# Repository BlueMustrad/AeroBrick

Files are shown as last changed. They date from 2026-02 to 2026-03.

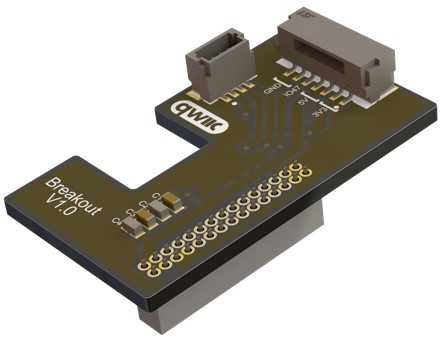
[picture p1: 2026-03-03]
Images/AeroBrick Breakout Board Image.jpg

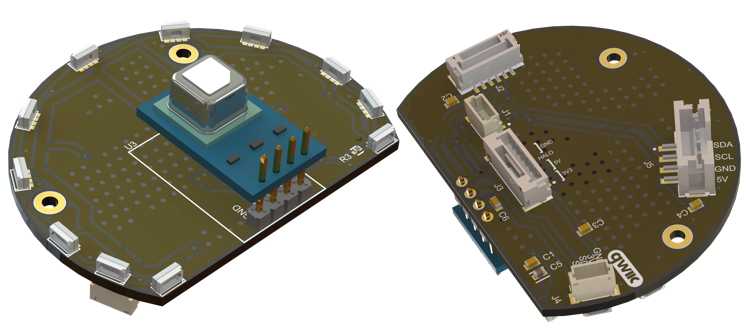
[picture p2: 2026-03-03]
Images/AeroBrick MainBoard Image.jpg

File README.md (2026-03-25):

# AERO BRICK
A fully open-source and easy-to-build air-quality monitor designed for workshops, maker spaces, and home labs. It continuously tracks particulate matter (PM1–PM10), CO₂, VOCs, temperature, humidity, pressure, and hazardous chemicals, turning the air into actionable data.

Long-term exposure to fumes and poor ventilation is a real concern, especially in the form of soldering, 3D printing, or working with chemicals. As someone who is always working on a project, I come in contact with these more often than I should. AeroBrick solves this in that it's built to live right next to your workbench or printers, providing real-time monitoring and alerts when air quality begins to degrade, so you can act immediately instead of guessing.

Now you may ask, "Can't I buy one from Amazon and have it in my workshop within a day?" To which I say that these off-the-shelf air-quality monitors can cost $300–$400 and track only basic metrics like temperature or generic VOC levels. Whereas AeroBrick can be assembled in just a few days, while having a hell of a time, using readily available components, resulting in lab-grade monitoring at a fraction of the cost.

# The Design
Go to the [Images folder](https://github.com/BlueMustrad/AeroBrick/tree/main/Images) for all pictures!

## THE [FULL ASSEMBLY](https://github.com/BlueMustrad/AeroBrick/blob/main/AeroBrick%20Full%20Assembly.step)!!


### Just the housing in [Fusion](https://github.com/BlueMustrad/AeroBrick/tree/main/3D%20Files/f3d%20Files):




### And in [Bambu Studio](https://github.com/BlueMustrad/AeroBrick/tree/main/3D%20Files/3mf%20Files) for 3D printing!


### To go with it, you also need these [PCBs](https://github.com/BlueMustrad/AeroBrick/tree/main/PCBs%20and%20Circuitry):




### [Schematic](https://github.com/BlueMustrad/AeroBrick/blob/main/Documents/AeroBrick%20Electrical%20Schematic.pdf)!
AeroBrick Electrical Schematic (2)_page-0001

# [Bill of Materials](https://github.com/BlueMustrad/AeroBrick/blob/main/AeroBrick%20Hardware%20BOM.csv)
Disclaimer: These prices do not factor in shipping or taxes!

| Item | Type | Quantity | Price (USD) | Item Total (USD) | Link |
|---|---|---|---|---|---|
| T-Display S3 Long | Screen | 1 | $32.13 | $32.13 | [LilyGo](https://lilygo.cc/en-us/products/t-display-s3-long?variant=44211063390389) |
| SEN54-SDN-T | Sensor | 1 | $26.85 | $26.85 | [DigiKey](https://www.digikey.com/en/products/detail/sensirion-ag/SEN54-SDN-T/15903868) |
| BME280 | Sensor | 1 | $14.95 | $14.95 | [DigiKey](https://www.digikey.com/en/products/detail/adafruit-industries-llc/2652/5604372) |
| SEN0377 | Sensor | 1 | $39.90 | $39.90 | [DigiKey](https://www.digikey.com/en/products/detail/dfrobot/SEN0377/15848107) |
| SCD41 | Sensor | 1 | $28.99 | $28.99 | [Amazon](https://www.amazon.com/HiLetgo-Temperature-Humidity-Communication-Monitoring/dp/B0CDWXWCS5) |
| Qwiic Cable (50mm) | Cable | 2 | $1.50 | $3.00 | [DigiKey](https://www.digikey.com/en/products/detail/sparkfun-electronics/17260/13629028) |
| JST GHR-06V-S | Connector | 2 | $0.15 | $0.30 | [DigiKey](https://www.digikey.com/en/products/detail/jst-sales-america-inc/GHR-06V-S/807818) |
| JST GHR-07V-S | Connector | 2 | $0.14 | $0.28 | [DigiKey](https://www.digikey.com/en/products/detail/jst-sales-america-inc/GHR-07V-S/807819) |
| JST PHR-4 | Connector | 2 | $0.10 | $0.20 | [DigiKey](https://www.digikey.com/en/products/detail/jst-sales-america-inc/PHR-4/608606) |
| Amphenol 68604-804HLF | Connector | 1 | $0.53 | $0.53 | [DigiKey](https://www.digikey.com/en/products/detail/amphenol-fci/68604-804HLF/11606373) |
| JST ASPHSPH24K51 | Connector | 4 | $0.33 | $1.32 | [DigiKey](https://www.digikey.com/en/products/detail/jst-sales-america-inc/ASPHSPH24K51/6009457) |
| JST AGHGH28K51 | Connector | 12 | $0.39 | $4.68 | [DigiKey](https://www.digikey.com/en/products/detail/jst-sales-america-inc/AGHGH28K51/6009448) |
| Custom Made Mainboard | PCB | 5 | $1.20 | $6.00 | JLCPCB (+ $10-15 for stencil) |
| Custom Made Breakout Board | PCB | 5 | $1.20 | $6.00 | JLCPCB (+ $10-15 for stencil) |
| Mainboard Components | Components | — | — | $21.00 | See [PCB files](https://github.com/BlueMustrad/AeroBrick/blob/main/PCBs%20and%20Circuitry/Main%20Board/AeroBrick%20Mainboard%20BOM.csv) for details |
| Breakout Board Components | Components | — | — | $7.00 | See [PCB files](https://github.com/BlueMustrad/AeroBrick/blob/main/PCBs%20and%20Circuitry/Breakout%20Board/AeroBrick%20Breakout%20BOM.csv) for details |
| Hardware Total (as of 02/26) | | | | $193.13 | |

| Item | Total Price | Description |
| ---- | --- | --- |
| Fasteners | $7 | Screws, heat-set inserts, bolts, and washers |
| PCB Stencils | $22.06 | Used to add solder paste to the bare PCB |
| Hidden Costs | ~$125 | Shipping/taxes/tariffs :( |
| **Final Total (as of 03/26)** | | **$347.19** |

### **Additional Considerations (see [Other Parts](https://github.com/BlueMustrad/AeroBrick/blob/main/README.md) for details), not included in the BOM:**
- Screws
- 3D-printing Filament
- Heat-set Inserts
- Solder Paste
- Superglue
- Isopropyl Alcohol

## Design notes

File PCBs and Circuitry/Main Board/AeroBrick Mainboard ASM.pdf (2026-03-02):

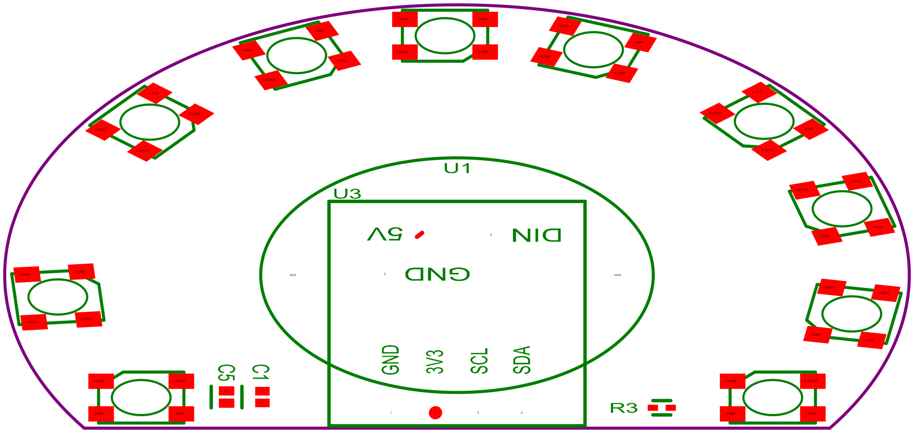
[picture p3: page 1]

4-DIN

1 -VD D

3 -GND

2-DOUT

4-DIN

3 -GND

1 -VDD

2 -D OUT

4 -D IN

1 -VD D

2 -D OUT

3 -GND

2

1

1 -VD D

1

2

2 -D OUT

MH1

4-DIN

3 -GND

3

1

1 -VD D

2-DOUT

1

2 | 3

4-DIN

3 -GND

2

4

2 -D OUT

1 -VD D

MH2

3 -GND

4-DIN

1 | 2

2-DOUT

4-DIN

3 -GND

1 -VD D

3 -GND

2-DOUT

4-DIN

1 -VD D

2 -D OUT

3-GND

3 -GND

2-DOUT

1 -VD D

4-DIN

4-DIN

1 -VD D

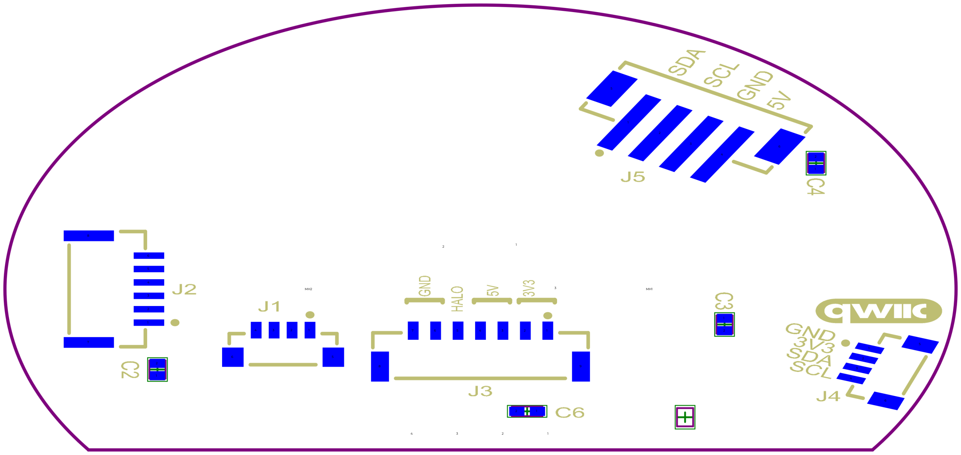
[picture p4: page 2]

87

654321

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
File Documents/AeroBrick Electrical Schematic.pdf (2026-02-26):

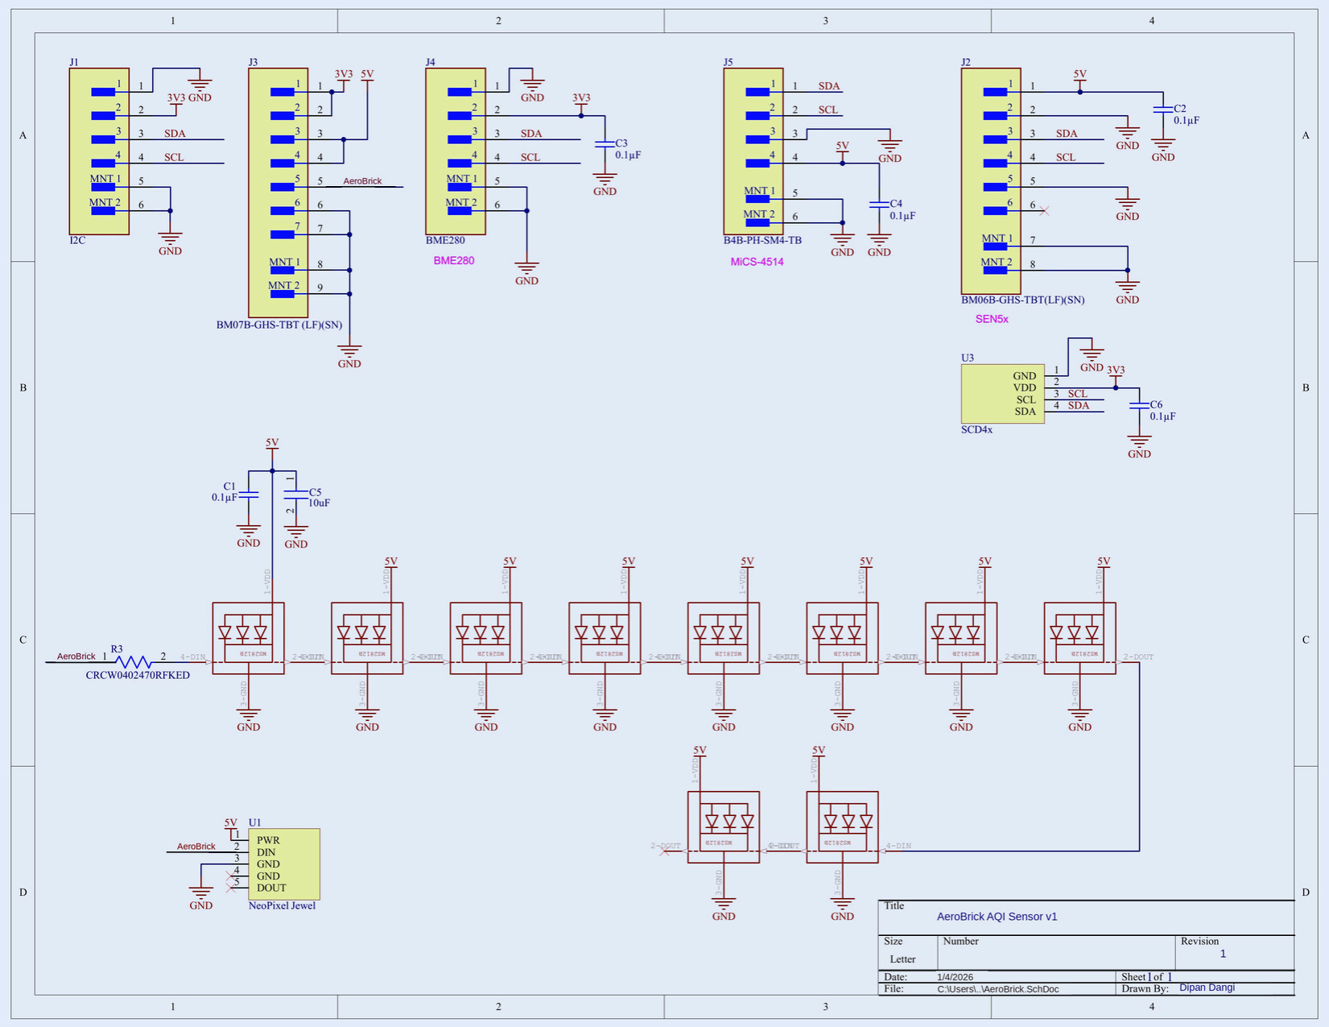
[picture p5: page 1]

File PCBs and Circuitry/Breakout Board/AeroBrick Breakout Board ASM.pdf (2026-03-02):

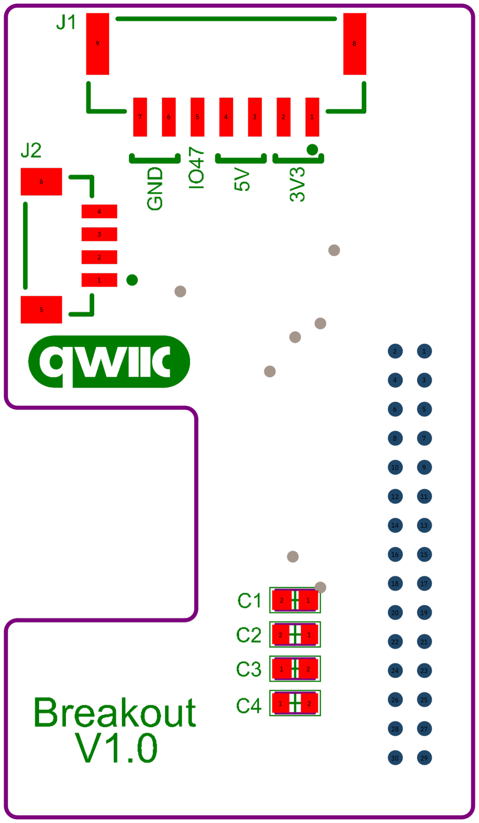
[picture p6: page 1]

65

94321

7

6

5

4

3

21212

12121

8

24681012141618202224262830

1357911131517192123252729

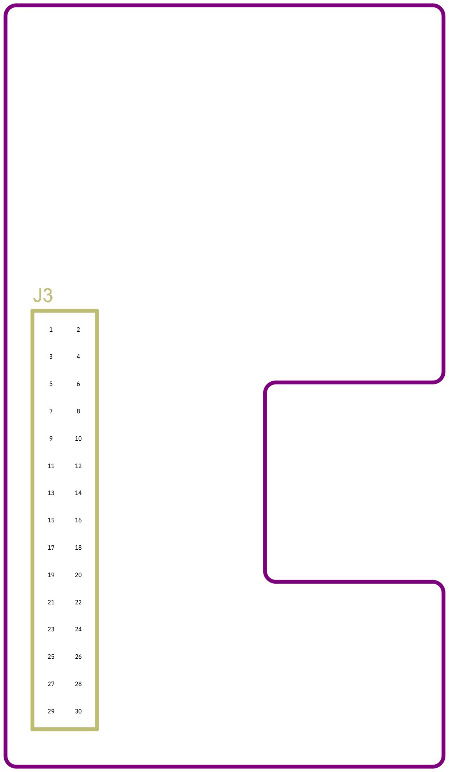
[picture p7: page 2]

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
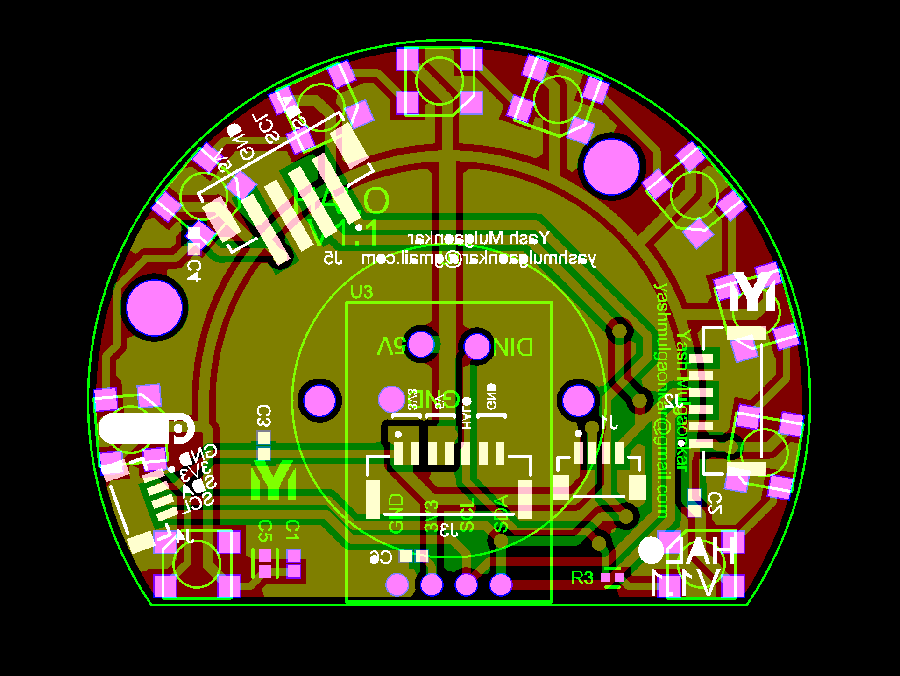
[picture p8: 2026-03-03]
Images/Mainboard PCB.png

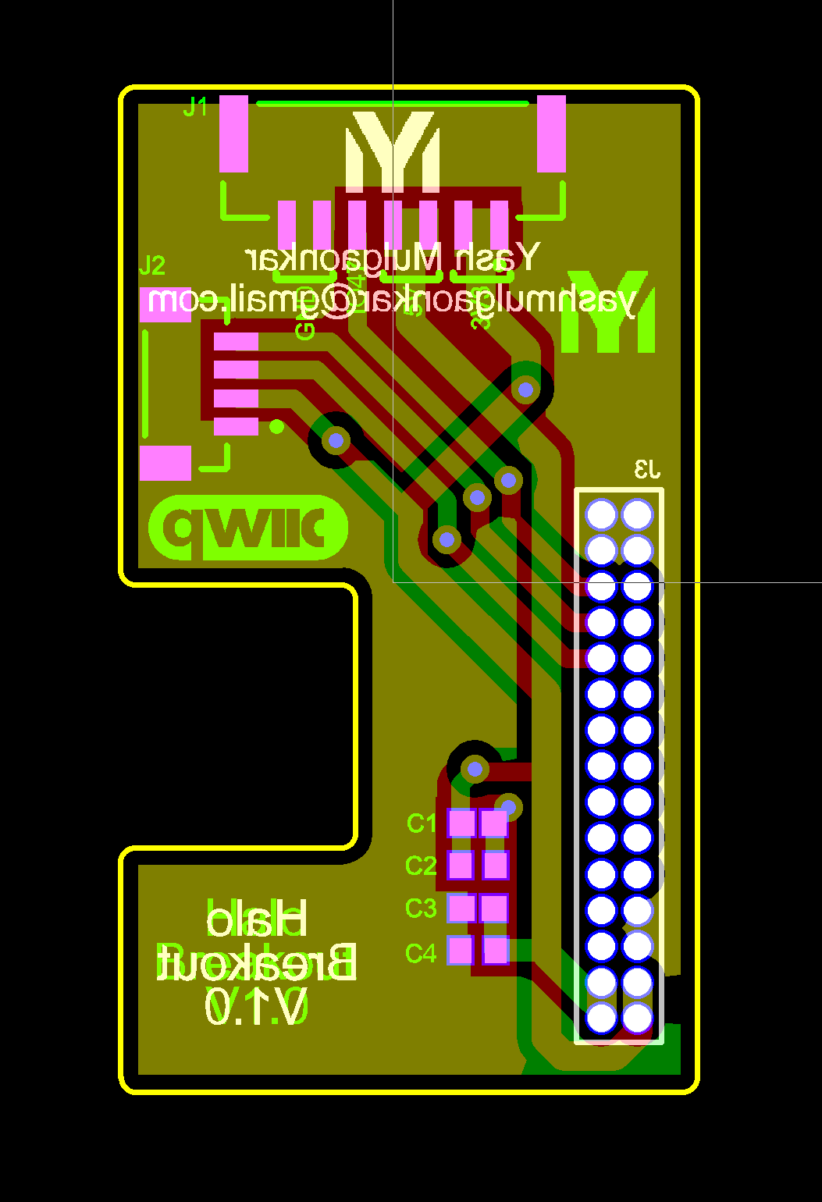
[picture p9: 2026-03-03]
Images/Breakout Board PCB.png

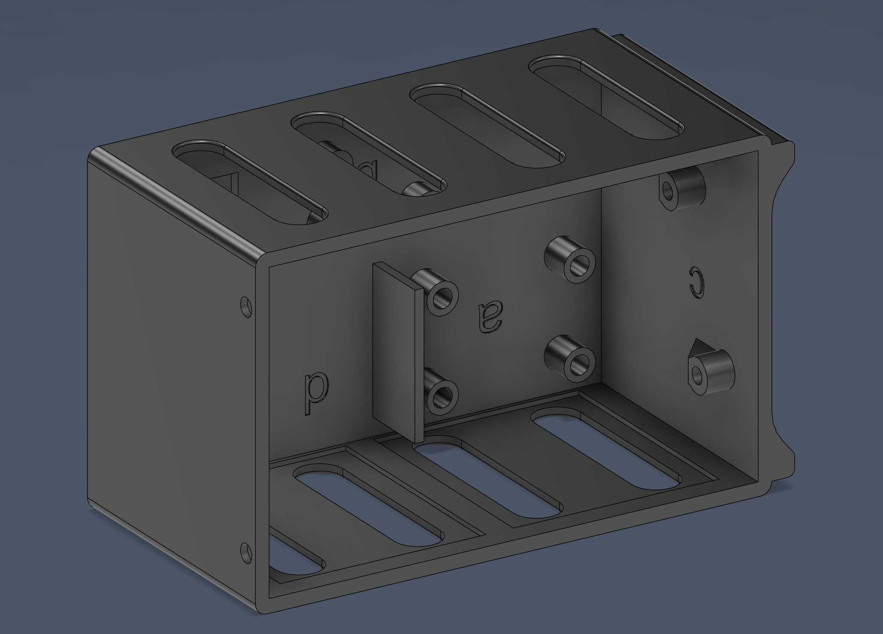
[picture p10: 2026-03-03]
Images/Main Housing in Fusion.png

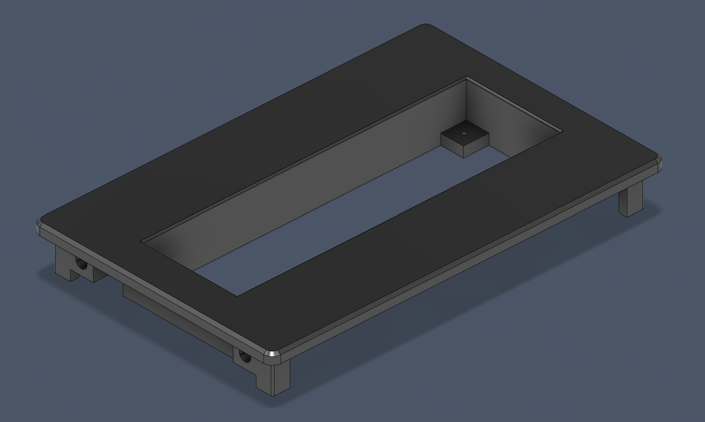
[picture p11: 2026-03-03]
Images/Top Housing in Fusion.png

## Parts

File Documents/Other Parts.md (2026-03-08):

# Other Parts BOM

### 3D Printed Parts
Ideally print in ASA, if not, PETG is the next best. Everything can be printed with 0.2 mm layers, 2 walls and 20-25% gyroid infill
| Part | Quantity | Notes |
|---|---|---|
| Main Housing | 1 | Supports not required but recomended |
| Top Housing | 1 | Supports are required |
| Side Hole Mesh | 4 | A 0.2mm nozzle is preferred for higher resolution |

---

### Hardware Parts

| Part | Quantity | Cost |
|---|---|---|
| M2 x 0.40mm Thread, 6mm Long Button Head Screw | 6 | $1.22 |
| M2 x 0.4mm Thread, 20mm Long Flat Head Screw | 6 | $4.95 |
| M2 x 0.40mm Thread, 8mm Long Button Head Screw | 4 | $1.02 |
| M2 x 0.4mm Thread, 6mm Long Flat Head Screw | 6 | $1.32 |
| M2 x 0.4mm, 4mm Installed Length Heat-Set Insert, Brass | 18 | $3.37 |
| M2.5 x 0.45mm, 5.6mm Installed Length Heat-Set Insert, Brass | 4 | $0.99 |
| M2.5 x 0.45mm Thread, 6mm Long Button Head Screw | 4 | $0.46 |

---

### Other Parts

| Part | Notes | Suggested |
|---|---|---|
| T4 Solder Paste | 30g syringe/tube, 138℃ Melting Point | [Amazon URL](https://www.amazon.com/gp/product/B0BLSJQPR6/ref=ox_sc_act_title_1?smid=A1NSYQXYRWRLYY&th=1) | 
| VHB Double Sided Tape | Non-conductive tape, 10mm in width and 1.1mm in thickness | [Amazon URL](https://www.amazon.com/Double-Mounting-0-025in-Strong-Adhesive/dp/B0CHDVNS5T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) |
| Cyanoacrylate (CA) Glue | A gel is recommended as it provides better control and is less likely to drip | [Amazon URL](https://www.amazon.com/Super-Glue-15185-12-Pack-07oz/dp/B004YEN37K?th=1) |

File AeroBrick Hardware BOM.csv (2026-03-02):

Item | Type | Quantity | Price (USD) | Item total (USD) | Link | Column 1
T-Display S3 Long | Screen | 1 | $32.13 | $32.13 | https://lilygo.cc/en-us/products/t-display-s3-long?variant=44211063390389
SEN54-SDN-T | Sensor | 1 | $26.85 | $26.85 | https://www.digikey.com/en/products/detail/sensirion-ag/SEN54-SDN-T/15903868
BME280 | Sensor | 1 | $14.95 | $14.95 | https://www.digikey.com/en/products/detail/adafruit-industries-llc/2652/5604372
SEN0377 | Sensor | 1 | $39.90 | $39.90 | https://www.digikey.com/en/products/detail/dfrobot/SEN0377/15848107
SCD41 | Sensor | 1 | $28.99 | $28.99 | https://www.amazon.com/HiLetgo-Temperature-Humidity-Communication-Monitoring/dp/B0CDWXWCS5
Qwiic Cable (50mm) | Cable | 2 | $1.50 | $3.00 | https://www.digikey.com/en/products/detail/sparkfun-electronics/17260/13629028
JST GHR-06V-S | Connector | 2 | $0.15 | $0.30 | https://www.digikey.com/en/products/detail/jst-sales-america-inc/GHR-06V-S/807818
JST GHR-07V-S | Connector | 2 | $0.14 | $0.28 | https://www.digikey.com/en/products/detail/jst-sales-america-inc/GHR-07V-S/807819
JST PHR-4 | Connector | 2 | $0.10 | $0.20 | https://www.digikey.com/en/products/detail/jst-sales-america-inc/PHR-4/608606
Amphenol 68604-804HLF | Connector | 1 | $0.53 | $0.53 | https://www.digikey.com/en/products/detail/amphenol-fci/68604-804HLF/11606373?curr=usd
JST ASPHSPH24K51 | Connector | 4 | $0.33 | $1.32 | https://www.digikey.com/en/products/detail/jst-sales-america-inc/ASPHSPH24K51/6009457?curr=usd
JST AGHGH28K51 | Connector | 12 | $0.39 | $4.68 | https://www.digikey.com/en/products/detail/jst-sales-america-inc/AGHGH28K51/6009448?curr=usd
Custom Made Mainboard | PCB | 5 | $1.20 | $6.00 | N/A on JLC PCB. Plus ~$7-12 for a stencil
Custom Made Breakout Board | PCB | 5 | $1.20 | $6.00 | N/A on JLC PCB. Plus ~$7-12 for a stencil
Mainboard Components | Components | N/A | N/A | $22.00 | See PCB Files for details
Breakout Board Componets | Components | N/A | N/A | $6.00 | See PCB Files for details
 |  |  |  | $193.13

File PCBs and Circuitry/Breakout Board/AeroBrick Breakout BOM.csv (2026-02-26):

Designator | Quantity | Manufacturer | Manufacturer Part Number | Description
C1, C3 | 2 | YAGEO | CC0603ZRY5V9BB104 | 0.1 µF -20%, +80% 50V Ceramic Capacitor Y5V (F) 0603 (1608 Metric)
C2, C4 | 2 | YAGEO | CC0603KRX5R8BB105 | 1 µF ±10% 25V Ceramic Capacitor X5R 0603 (1608 Metric)
J1 | 1 | JST Sales America Inc. | SM07B-GHS-TB | Connector Header Surface Mount, Right Angle 7 position 0.049" (1.25mm)
J2 | 1 | JST Sales America Inc. | BM04B-SRSS-TBT | Connector Header Surface Mount 4 position 0.039" (1.00mm)
J3 | 1 | Amphenol ICC (FCI) | 20021311-00030T4LF | 30 Position Receptacle Connector 0.050" (1.27mm) Through Hole Gold

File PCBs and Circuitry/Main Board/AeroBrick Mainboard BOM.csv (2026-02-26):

Designator | Quantity | Manufacturer | Manufacturer Part Number | Description
C1, C2, C3, C4, C6 | 5 | YAGEO | CC0603ZRY5V9BB104 | 0.1 µF -20%, +80% 50V Ceramic Capacitor Y5V (F) 0603 (1608 Metric)
C5 | 1 | Murata Electronics | GRM188R6YA106MA73D | 10 µF ±20% 35V Ceramic Capacitor X5R 0603 (1608 Metric)
J1, J4 | 2 | JST Sales America Inc. | BM04B-SRSS-TBT | Connector Header Surface Mount 4 position 0.039" (1.00mm)
J2 | 1 | JST Sales America Inc. | BM06B-GHS-TBT | Connector Header Surface Mount 6 position 0.049" (1.25mm)
J3 | 1 | JST Sales America Inc. | BM07B-GHS-TBT | Connector Header Surface Mount 7 position 0.049" (1.25mm)
J5 | 1 | JST Sales America Inc. | B4B-PH-SM4-TB | Connector Header Surface Mount 4 position 0.079" (2.00mm)
LED1, LED2, LED3, LED4, LED5, LED6, LED7, LED8, LED9, LED10 | 10 | Adafruit | 1655 | NeoPixel 5050 RGB LED with Integrated Driver
R3 | 1 | Vishay Dale | CRCW0402470RFKED | 470 Ohms ±1% 0.063W, 1/16W Chip Resistor 0402 (1005 Metric) Automotive AEC-Q200 Thick Film
U3 | 1 | Sensirion | SCD41 | HiLetgo SCD41 CO2 Carbon Dioxide Sensor (Amazon 14mm x 20mm modules)
U1 | 1 | Adafruit | 2226 | NeoPixel Jewel - 7 x 5050 RGB LED with Integrated Drivers

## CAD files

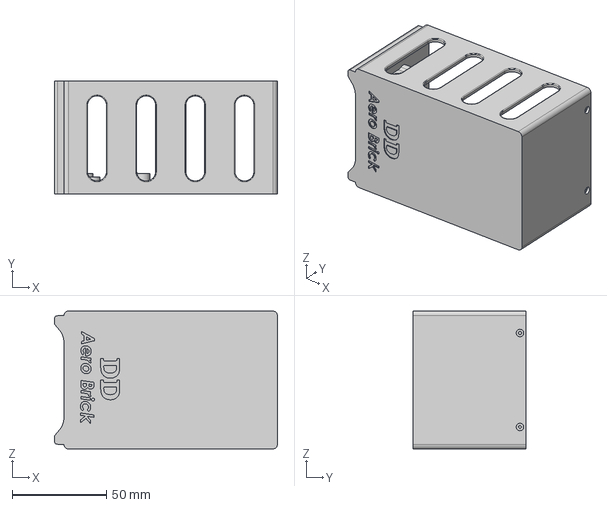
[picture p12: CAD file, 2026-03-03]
3D Files/STEP Files/Aero Brick - Main Housing v1.1.step
118.0 x 60.0 x 73.0 mm

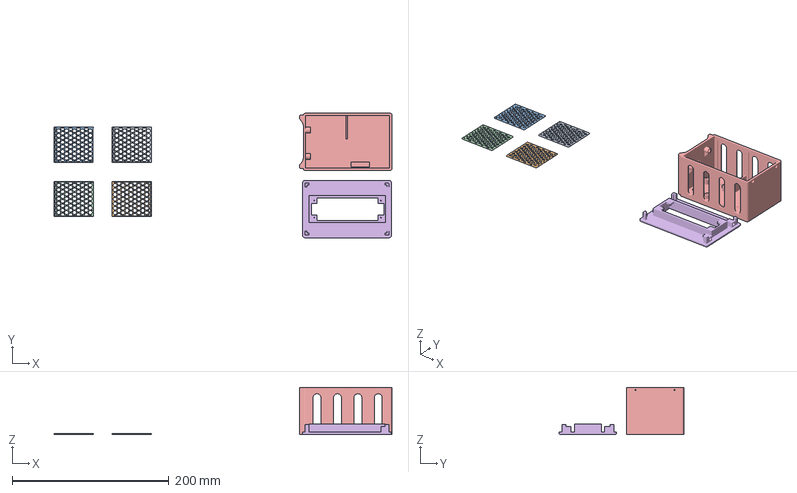
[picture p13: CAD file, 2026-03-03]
3D Files/3mf Files/Aero Brick.3mf
430.7 x 158.7 x 60.0 mm
Assembly x 4
Aero Brick - Main Housing v1.1.step
Aero Brick - Top v1.1.step

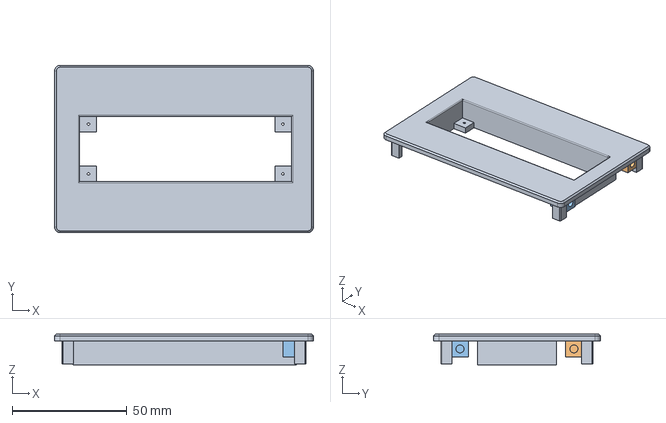
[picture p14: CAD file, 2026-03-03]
3D Files/STEP Files/Aero Brick - Top v1.1.step
113.0 x 73.0 x 13.5 mm

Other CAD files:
3D Files/f3d Files/Aero Brick - Main Housing v1.1.f3d
3D Files/f3d Files/Aero Brick - Top v1.1.f3d

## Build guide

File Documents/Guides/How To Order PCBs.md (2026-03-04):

# How To Order PCBs

All the PCB Gerber files and corresponding BOMs are included in the **Electrical Hardware** folder. You can order the PCBs from any fabrication house of your preference. I usually use JLCPCB, and if you opt to use them, here's a guide to help you place your order. The process is quite similar across most other PCB fabrication services.

---

## Before You Start: Verify Your Gerber Files

It's good practice to visually inspect your Gerber files before uploading them to a fab house. Use a free online viewer to make sure all layers look correct:

- [Tracespace Viewer](https://tracespace.io/view/) — great for layer-by-layer inspection
- [JLCPCB Gerber Viewer]([https://gerber-viewer.jlcpcb.com](https://jlcpcb.com/RGE)) — shows exactly how JLCPCB will interpret your files

---

## Step 1: Create an Account on JLCPCB

1. Visit the [JLCPCB website](https://jlcpcb.com).
2. Sign up for a free account if you don't already have one.
3. Log in to access the ordering interface.

---

## Step 2: Upload the Halo Gerber Files from this GitRepo, [here](https://github.com/BlueMustrad/AeroBrick/tree/main/PCBs%20and%20Circuitry)

1. On the JLCPCB homepage, drag and drop the Halo Gerber file package into the **"Add Gerber file"** container.

> 💡 JLCPCB accepts `.zip` files, keep your Gerbers zipped, don't upload individual files.

---

## Step 3: Configure Your PCB Options

Once the Gerber files are uploaded, customize the PCB specifications:

### Basic Options

| Option | Value |
|---|---|
| Layer Count | 2 (both AeroBrick PCBs are 2-layer) |
| Dimensions | Auto-detected from the Gerber files |
| Quantity | Choose the number of PCBs you need |
| Thickness | 1.6mm (recommended) |
| Material | FR4 |

### Advanced Options

| Option | Value |
|---|---|
| Solder Mask Color | Pick any color you prefer |
| Silkscreen Color | White or black (depending on solder mask) |
| Surface Finish | Your preference, I usually do Lead Free HASL |
| Via Options | Tenting |

> Leave all other options as default.

---

## Step 4: Review Pricing and Shipping Costs

JLCPCB provides a real-time cost estimate based on your selected options. Make sure to review:

- PCB production costs
- Shipping options and costs

Shipping options include DHL, FedEx, and standard post. Choose one based on your budget and urgency.

> 💡 **Pro Tip:** JLCPCB frequently offers new-user coupons that bring 5 PCBs down to $2/5. Check their promotions page before checking out.

---

## Step 5: Add Additional Services (Optional)

JLCPCB offers additional services, such as:

- **SMT Assembly:** if you need components assembled on your board
- **Solder Stencil:** for solder paste application during assembly

If required, configure these services before proceeding.

> 💡 **SMT Assembly tip:** If using SMT assembly, make sure your BOM uses LCSC part numbers, as JLCPCB sources components directly from LCSC and will match by those IDs. You can look up parts at [lcsc.com](https://lcsc.com).

---

## Step 6: Place Your Order

1. Add the order to your cart.
2. Proceed to checkout and provide your shipping address.
3. Choose your preferred shipping method.

---

## Step 7: Make Payment

Complete the payment to finalize your order.

---

## Step 8: Track Your Order

After payment, JLCPCB will start production. You can track the production status and shipping updates from your account dashboard.

> 💡 JLCPCB typically takes 24–48 hours for production on standard 2-layer boards. Shipping time varies by method but DHL is usually 3–5 business days to the US.

---

## Step 9: Now just wait patiently, or impatiently...

---

## Pre-Order Checklist

Before hitting that order button, run through this quick checklist:

- [ ] Gerber files verified in a viewer
- [ ] Board dimensions look correct after upload
- [ ] Layer count is set to 2
- [ ] Quantity is correct
- [ ] Shipping address is correct
- [ ] Applied any available coupons/discounts
- [ ] If using SMT assembly: BOM and CPL (component placement) files are uploaded

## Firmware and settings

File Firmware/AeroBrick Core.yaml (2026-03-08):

#Define Project
substitutions:
  name: aerobrick
  version: "26.1.9.2"
  device_description: ${name} - v${version}.

psram:
  mode: octal
  # speed: 120MHz

esp32:
  board: esp32-s3-devkitc-1
  flash_size: 16MB
  cpu_frequency: 240MHz
  framework:
    type: esp-idf
    advanced:
      enable_idf_experimental_features: true
    # platform_version: 6.9.0
    # version: 5.3.1

esp32_improv:
  authorizer: none

external_components:
  - source: github://BlueMustard/esphome-components
    components: [axs15231, sy6970]

  - source: github://pr#7770 # RMT driver, remove rmt_channel when using esp-idf
    components: [ remote_base, remote_receiver, remote_transmitter, esp32_rmt, esp32_rmt_led_strip ]
    refresh: 0s


spi:
  id: lily_spi
  type: quad
  clk_pin: 17
  data_pins:
    - 13
    - 18
    - 21
    - 14

captive_portal:

logger:
  level: DEBUG

globals:
  - id: cycleCounter
    type: int
    restore_value: no
    initial_value: '0'
  - id: temp_unit_changed
    type: bool
    initial_value: "true"

switch:
  - platform: template
    name: "Startup Light Blink"
    id: startup_light_blink
    icon: mdi:lightbulb
    restore_mode: RESTORE_DEFAULT_ON
    optimistic: true
    entity_category: "config"
  - platform: template
    name: "24h Clock Format"
    id: time_format
    icon: mdi:clock-digital
    restore_mode: RESTORE_DEFAULT_OFF
    optimistic: true
    entity_category: "config"

select:
  - platform: template
    name: Display Temperature Unit
    id: display_temperature_unit
    entity_category: "Config"
    options:
     - "Fahrenheit"
     - "Celsius"
     - "Kelvin"
    initial_option: "Fahrenheit"
    restore_value: true
    optimistic: true
    on_value:
      - globals.set:
          id: temp_unit_changed
          value: "true"

interval:
  - interval: 10s
    then:    
      if:
        condition:
          wifi.connected:
        then:
          - lvgl.widget.update:
              id: wifi_stat
              text_color: my_green
          - lvgl.widget.show:
              id: maker_logo              
        else:
          - lvgl.widget.update:
              id: wifi_stat
              text_color: my_red

  - interval: 1s
    then:
      - script.execute: time_update  

  - interval: 1s
    then:
      - if:
          condition:
            - binary_sensor.is_off: ink_ha_connected
            - lambda: 'return id(cycleCounter) < 30;'
            - switch.is_on: startup_light_blink

          then:
            - light.turn_on:
                id: rgb_light
                effect: "Rainbow Effect With Custom Values"
            - lambda: 'id(cycleCounter) += 1;'

  - interval: 1s
    then:
      - if:
          condition:
            - binary_sensor.is_off: ink_ha_connected
            - lambda: 'return id(cycleCounter) > 30;'
            - lambda: 'return id(cycleCounter) < 31;'
            - switch.is_on: startup_light_blink

          then:
            - light.turn_off:
                id: rgb_light
            - lambda: 'id(cycleCounter) += 1;'              

api:
  on_client_connected:
      - delay: 1s
      - light.turn_off: rgb_light
      - lambda: 'id(cycleCounter) = 30;'    
  services:
    #Co2 Calibration Service
    - service: calibrate_co2_value
      variables:
        co2_ppm: float
      then:
        - scd4x.perform_forced_calibration:
            value: !lambda "return co2_ppm;"
            id: scd40
    - service: sen55_clean
      then:
        - sen5x.start_fan_autoclean: sen55    

i2c:
  - sda: 9
    scl: 48
    id: lily_i2c
  - sda: 15
    scl: 10
    id: touch_i2c

output:
  - platform: ledc
    pin: 1
    id: backlight
    frequency: 100Hz  #Datasheet suggests low-frequency PWM. Should prevent stability issues.
    
# sy6970:
#   i2c_id: touch_i2c
#   state_led_enable: false  # To turn off the blinking green status LED

display:
  - platform: qspi_dbi
    id: lily_display
    model: AXS15231
    spi_id: lily_spi
    dimensions:
      height: 640
      width: 180
    cs_pin: 12
    reset_pin: 16
    rotation: 0
    auto_clear_enabled: false

touchscreen:
  - platform: axs15231
    id: lily_touch
    display: lily_display
    i2c_id: touch_i2c
    interrupt_pin: GPIO11
    transform:
      mirror_x: false
      mirror_y: false
      swap_xy: false
    on_touch:
      - lambda: |-
            ESP_LOGI("cal", "x=%d, y=%d, x_raw=%d, y_raw=%0d",
            touch.x,
            touch.y,
            touch.x_raw,
            touch.y_raw
            );

web_server:
  port: 80

image:
  - file: https://github.com/BlueMustrad/AeroBrick/blob/main/Assets/maker_logo.png
    id: maker_logo
    resize: 25x25
    type: RGB565
    transparency: alpha_channel
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

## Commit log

2026-03-02 Update and rename AeroBrick Bill of Materials - Sheet1.csv to AeroBrick BOM.csv
    [AeroBrick BOM.csv]
2026-03-03 Rename Screenshot 2026-02-24 171738.png to Main Housing in Fusion
2026-03-03 Rename Main Housing in Fusion to Main Housing in Fusion.png
2026-03-03 Rename Screenshot 2026-02-24 171836.png to Top Housing in Fusion.png
2026-03-03 Rename Screenshot 2026-02-25 000227.png to Mainboard PCB.png
2026-03-03 Rename Screenshot 2026-02-25 000406.png to Breakout Board PCB.png
2026-03-03 Rename Screenshot 2026-03-02 225411.png to Full Top Assembly in Fusion.png
2026-03-03 Rename Screenshot 2026-03-02 225307.png to Full Main Assembly in Fusion.png
2026-03-03 Update and rename AeroBrick BOM.csv to AeroBrick Hardware BOM.csv
    [AeroBrick Hardware BOM.csv]
2026-03-04 Create How To Order PCBs.md
2026-03-04 Update How To Order PCBs.md
2026-03-08 Create Physical Assembly.md
